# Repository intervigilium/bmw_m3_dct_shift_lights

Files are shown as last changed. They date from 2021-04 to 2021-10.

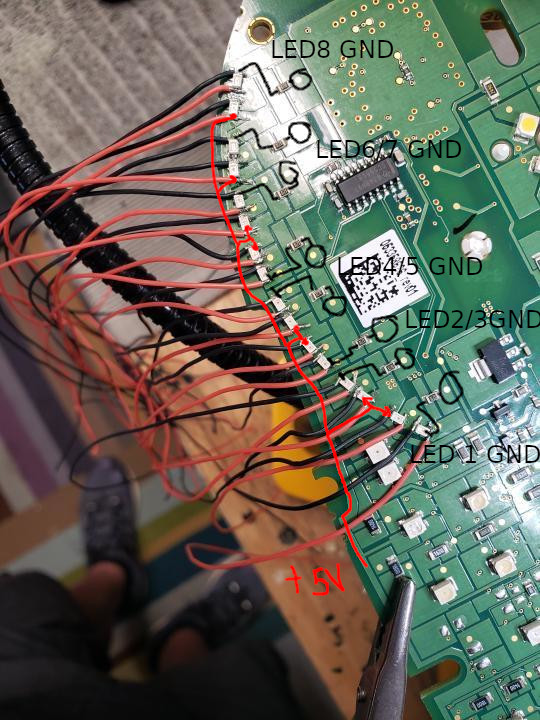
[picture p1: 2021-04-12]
m3_dct_shift_lights/m3_dct_cluster_gnd_points.jpg

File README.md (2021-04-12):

# BMW M3 DCT Cluster Shift Lights Retrofit

## BMW M3 DCT Cluster
The M3 DCT instrument cluster has a series of 8 shift lights above the
tachometer. These shift lights are normally not active, and do not appear to
be possible to activate without having the DCT itself. Fortunately, the
cluster's LEDs can be driven by attaching leads to the test points on the
ground side, as the LEDs are connected to an onboard 5V rail for power, and
a TI 6C596G4 8-bit shift register which acts as a current sink to ground.
Grounding each of these LED pairs will light up the corresponding pair.

## Retrofit circuit
Instead of attempting to drive the LEDs using the onboard TI 6C596 shift
register, we can just connect the LEDs to a shift register of our own and
connect that to an Arduino. The sketch here assumes that the shift register
is a TI 6C596 as well, and is configured using pins D3-D5, D18-D19. Engine
RPM for the BMW E9X series appears to be present on OBD2 port pin 9 as a 12V
square wave. This circuit utilizes the 12V RPM signal input circuit from
the Chippernut digital shift light project to read the signal, as well as
the 5V buck regulator input circuit to provide power.

## Cluster modifications
The M3 DCT cluster modifications necessary are detailed in the
`m3_dct_cluster_gnd_points.jpeg` file. Ignore the leads from the LEDs
themselves. The important points are circled in black, and correspond to the
ground points for the LED pairs. It is necessary to attach leads to these
ground points ONLY. You MUST attach leads to the test points AFTER the 127 Ohm
resistor (the highlighted points ONLY), not before. Failure to follow this
instruction will result in burning out the LEDs due to overcurrent.
You will also need to cut a small hole in the cluster enclosure to allow the LED
ground lines to connect to the Arduino.

## Schematic
The included `m3_dct_shift_lights.sch` file can be opened with any Eagle
schematic compatible program. The schematic only includes the circuit necessary
to read the RPM and control the LEDs. It does NOT include the necessary circuit
to independently power the Arduino from the car's +12V power sources. The
Chippernut development board
(<https://www.chippernut.com/store/p31/Chipperkit.html>) comes with a power
pack consisting of a 5V buck converter that can be used for this purpose.

## Components
The included `bom_m3_dct_shift_lights.csv` file contains the list of parts
necessary to build the circuit. The BOM list can easily purchased on Digikey.
It does not include the Arduino or a board to mount all the components. I
highly suggest using the above linked Chippernut development board pack, as it
comes with the 5V buck converter as well as a development board, Arduino nano,
and enclosure for installation.

## Installation
You will need to tap pin 9 of the OBD2 port for the tachometer signal. This
needs to be connected where the schematic says "To OBD2 Pin 9". You will also
need to provide power and ground, as well as connecting the 8 LED ground lines
from the M3 DCT cluster to the shift register (Refer to schematic where it
details the LED pairs with the notes that these are on board). I suggest
tapping +12V power and ground from the cluster connector pins 9 (+12V) and
18 (ground). I suspect the circuit must be connected to the cluster's ground
in order for the LEDs to function. The Arduino and wires can be tucked into
the driver's footwell under the panel. I chose to zip tie it near the firewall.

## Software Notes
The Arduino sketch has a few constants that can be customized to suit your
needs. The activation RPM and the maximum RPM values can be found at the top
of the file with the names `kActivationRpm` and `kMaxRpm`, respectively. The
`kActivationRpm` variable sets the RPM value at which the first LED will light.
The `kMaxRpm` variable sets the RPM value at which the all the LEDs will start
to flash. Any RPM value above the `kMaxRpm` value will mean the LEDs continue
to flash until the RPM drops below the threshold.

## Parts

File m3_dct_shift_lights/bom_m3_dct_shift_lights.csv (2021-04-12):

Manufacturer Part Number | Manufacturer | Digi-Key Part Number | Customer Reference | Reference Designator | Packaging | Part Status | Quantity | Unit Price | Extended Price | Quantity Available | Mfg Std Lead Time | Description | RoHS Status | Lead Free Status | REACH Status
SFH618A-2 | Vishay Semiconductor Opto Division | SFH618A-2-ND |  |  | Tube | Active | 1 | 0.97000 | $0.97 | 1754 | 37 Weeks | OPTOISOLATOR 5.3KV TRANS 4-DIP | ROHS3 Compliant | Lead free | Not Available
2N3906-G | Comchip Technology | 641-1946-ND |  |  | Bag | Active | 1 | 0.21000 | $0.21 | 15038 | 32 Weeks | TRANS PNP 40V 0.2A TO92 | ROHS3 Compliant | Lead free | REACH Unaffected
1N4148TA | ON Semiconductor | 1N4148TACT-ND |  |  | Cut Tape (CT) | Active | 1 | 0.10000 | $0.10 | 116115 | 34 Weeks | DIODE GEN PURP 100V 200MA DO35 | ROHS3 Compliant | Lead free | REACH Unaffected
MFP-25BRD52-10K | Yageo | 10KADCT-ND |  |  | Cut Tape (CT) | Active | 2 | 0.70000 | $1.40 | 213280 | 20 Weeks | RES 10K OHM 1/4W 0.1% AXIAL | ROHS3 Compliant | Lead free | REACH Unaffected
CF14JT7K50 | Stackpole Electronics Inc | CF14JT7K50CT-ND |  |  | Cut Tape (CT) | Active | 1 | 0.10000 | $0.10 | 26444 | 24 Weeks | RES 7.5K OHM 1/4W 5% AXIAL | ROHS3 Compliant | Lead free | REACH Unaffected
CF14JT47K0 | Stackpole Electronics Inc | CF14JT47K0CT-ND |  |  | Cut Tape (CT) | Active | 1 | 0.10000 | $0.10 | 190229 | 24 Weeks | RES 47K OHM 1/4W 5% AXIAL | ROHS3 Compliant | Lead free | REACH Unaffected
TPIC6C596N | Texas Instruments | 296-9015-5-ND |  |  | Tube | Active | 1 | 1.57000 | $1.57 | 794 | 6 Weeks | IC 8 BIT SHIFT REGISTER 16-DIP | ROHS3 Compliant | Lead free | REACH Unaffected

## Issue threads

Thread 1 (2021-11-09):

CAN bus suggestion

dzid26, 2021-11-09:
Cool project.
You could also use engine load to determine the optimal shiftpoints. (You can calculate optimal shift points for max acceleration based on [engine torque and known gear ratios](https://glennmessersmith.com/shiftpt.html#data), - though for non-turbo it's probably at top RPM anyways.. https://www.youtube.com/watch?v=zZBqb0ZJSwU)

Anyway, if you'd like, you can find engine torque on PT-CAN.
This message:
https://github.com/dzid26/opendbc-BMW-E8x-E9x/blob/59a48a6f48a842bf6da671ec5830d79149100d7a/bmw_e9x_e8x.dbc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
and this https://github.com/dzid26/opendbc-BMW-E8x-E9x/blob/59a48a6f48a842bf6da671ec5830d79149100d7a/bmw_e9x_e8x.dbc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

----------
The shift-lights CAN message is [**0x206**](https://www.spoolstreet.com/threads/m-drive-and-mdm-in-non-m-cars.7155/post-117085).

dzid26, 2021-12-07:
The shift-lights CAN message is [**0x206**](https://www.spoolstreet.com/threads/m-drive-and-mdm-in-non-m-cars.7155/post-117085).

dzid26, 2022-10-28:
He has done it https://github.com/superwofy/E9X-M-CAN-Integration-Module

Closed 2021-12-07.

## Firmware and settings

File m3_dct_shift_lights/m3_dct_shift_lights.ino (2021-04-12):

#include <avr/sleep.h>

const int kNumLeds = 8;
const int kIlluminationTimeMs = 200;

const int kShiftClockPin = 3;
const int kShiftRegClockPin = 6;
const int kShiftSerialInPin = 5;
const int kShiftClearPin = A3;
const int kShiftOutputEnablePin = A2;

const int kActivationRpm = 4000;
const int kMaxRpm = 6500;

struct Tach {
  volatile unsigned long interval;
  volatile unsigned long lastPulseTime;
  volatile int timeoutCounter;
  long currentRpm;
  int timeoutValue;
  int rpmPerPulse;
  int rpmPin;
};
struct Tach gTach;

struct Debug {
  bool enabled;
  int rpmDirection;
  int rpmSlope;
  int lastDebugRpm;
};
struct Debug gDebug;

struct Serial {
  bool enabled;
  uint64_t numCycles;
};
struct Serial gSerial;

void setupDebugMode(struct Debug& d) {
  const bool kDebug = false;
  const int kDebugRpmSlope = 200;

  d.enabled = kDebug;
  d.rpmDirection = 1;
  d.rpmSlope = kDebugRpmSlope;
  d.lastDebugRpm = kActivationRpm - d.rpmSlope;
}

void setupSerial(struct Serial& s) {
  const bool kEnableSerial = false;
  if (!kEnableSerial) {
    return;
  }

  s.enabled = kEnableSerial;
  s.numCycles = 0;

  Serial.begin(9600);
}

void printRpm(const struct Serial s, const int rpm) {
  if (!s.enabled) {
    return;
  }
  if (s.numCycles % 5 == 0) {
    Serial.print("Current RPM: ");
    Serial.print(rpm);
    Serial.println();
  }
}

void printLights(const struct Serial s, const int numLights) {
  if (!s.enabled) {
    return;
  }
  if (s.numCycles % 5 == 0) {
    Serial.print("LEDs to light: ");
    Serial.print(numLights);
    Serial.println();
  }
}

void updateCycles(struct Serial& s) {
  if (!s.enabled) {
    return;
  }
  s.numCycles++;
}

void enableLightOutput(bool enable) {
  // This pin is active-low
  digitalWrite(kShiftOutputEnablePin, enable ? LOW : HIGH);
}

void enableLightsUpTo(int idx) {
  if (idx < 0 || idx > kNumLeds) {
    return;
  }
  digitalWrite(kShiftRegClockPin, LOW);
  shiftOut(kShiftSerialInPin, kShiftClockPin, MSBFIRST, (1 << idx) - 1);
  digitalWrite(kShiftRegClockPin, HIGH);
}

void blinkLights(int interval) {
  digitalWrite(kShiftOutputEnablePin, HIGH);
  delay(interval / 2);
  digitalWrite(kShiftOutputEnablePin, LOW);
  delay(interval / 2);
}

int calculateNumLights(int currentRpm, int activationRpm, int maxRpm, int numLeds) {
  if (currentRpm < activationRpm) {
    return 0;
  }
  // 1 LED at activation RPM, all 8 LEDs at just under max RPM
  return 1 + ((numLeds * (currentRpm - activationRpm)) / (maxRpm - activationRpm));
}

int generateDebugRpm(struct Debug& d) {
  int rpm = d.lastDebugRpm;
  d.lastDebugRpm += (d.rpmSlope * d.rpmDirection);
  if (d.lastDebugRpm > (kMaxRpm + d.rpmSlope) ||
      d.lastDebugRpm < (kActivationRpm - d.rpmSlope)) {
    d.rpmDirection = -1 * d.rpmDirection;
  }
  return rpm;
}

int readRpm(struct Tach& t) {
  if (t.timeoutCounter > 0) {
    // Check for RPM signal shutting down
    t.timeoutCounter--;
  }
  if (t.timeoutCounter <= 0) {
    t.currentRpm = 0;
    return t.currentRpm;
  }

  // Calculate effective pulse interval in Hz
  float pulseRate = 1 / (t.interval * 1e-6);
  t.currentRpm = pulseRate * t.rpmPerPulse;
  return t.currentRpm;
}

void doSleep(const struct Tach t, const struct Serial s) {
  if (t.timeoutCounter > 0) {
    return;
  }
  sleep_enable();
  set_sleep_mode(SLEEP_MODE_PWR_DOWN);
    if (s.enabled) {
    Serial.println("Suspending due to no RPM input");
  }
  // Add delay to allow LED shutdown
  digitalWrite(LED_BUILTIN, LOW);
  delay(200);
  sleep_cpu();
}

void exitSleep(const struct Tach t) {
  // Sleep occurs if timeout counter drops below 1
  if (t.timeoutCounter > 0) {
    return;
  }
  digitalWrite(LED_BUILTIN, HIGH);
  sleep_disable();
}

void rpmIsr() {
  // Disable sleep mode if RPM ISR occurs while sleeping
  exitSleep(gTach);
  unsigned long now = micros();
  gTach.interval = now - gTach.lastPulseTime;
  gTach.lastPulseTime = now;
  gTach.timeoutCounter = gTach.timeoutValue;
}

void setupBuiltInLed() {
  pinMode(LED_BUILTIN, OUTPUT);
  digitalWrite(LED_BUILTIN, HIGH);
}

void setupShiftRegisterPins() {
  pinMode(kShiftSerialInPin, OUTPUT);
  pinMode(kShiftClockPin, OUTPUT);
  pinMode(kShiftRegClockPin, OUTPUT);
  pinMode(kShiftClearPin, OUTPUT);
  pinMode(kShiftOutputEnablePin, OUTPUT);

  // clear registers (active-low)
  digitalWrite(kShiftClearPin, LOW);
  delay(100);
  digitalWrite(kShiftClearPin, HIGH);
}

void setupRpmCalculation(struct Tach& t) {
  // number of cycles until until idle once RPM signal stops coming
  const int kTimeoutValue = 20;
  // BMW N51/N52 is 50Hz == 1000 RPM, 100Hz = 2000 RPM, or 20 RPM per pulse
  const int kRpmPerPulse = 20;
  // Pins 2/3 are the only external interrupt pins available on nano
  const int kRpmPin = 2;

  t.interval = 0;
  t.lastPulseTime = 0;
  t.timeoutCounter = 0;
  t.currentRpm = 0;
  t.timeoutValue = kTimeoutValue;
  t.rpmPerPulse = kRpmPerPulse;
  t.rpmPin = kRpmPin;

  pinMode(t.rpmPin, INPUT);
  attachInterrupt(digitalPinToInterrupt(t.rpmPin), rpmIsr, RISING);
}

// the setup routine runs once when you press reset:
void setup() {
  setupBuiltInLed();

  setupDebugMode(gDebug);

  setupSerial(gSerial);

  setupShiftRegisterPins();

  setupRpmCalculation(gTach);
}

// the loop routine runs over and over again forever:
void loop() {
  int rpm = gDebug.enabled ? generateDebugRpm(gDebug) : readRpm(gTach);
  printRpm(gSerial, rpm);
  int numLights = calculateNumLights(rpm, kActivationRpm, kMaxRpm, kNumLeds);
  printLights(gSerial, numLights);
  if (numLights > kNumLeds) {
    enableLightOutput(true);
    enableLightsUpTo(kNumLeds);
    blinkLights(kIlluminationTimeMs);
  } else if (numLights > 0) {
    enableLightOutput(true);
    enableLightsUpTo(numLights);
    delay(kIlluminationTimeMs);
  } else {
    // No lights enabled
    enableLightOutput(false);
    delay(kIlluminationTimeMs);
  }
  updateCycles(gSerial);
  doSleep(gTach, gSerial);
}

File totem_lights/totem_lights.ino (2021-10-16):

#include <Adafruit_NeoPixel.h>
#ifdef __AVR__
#include <avr/power.h>
#endif
#define PIN        6
#define NUMPIXELS 60

#define LED_BRIGHTNESS 200

#define NUM_MODES 4
int *counter;

Adafruit_NeoPixel pixels(NUMPIXELS, PIN, NEO_GRB + NEO_KHZ800);

void setup() {
  counter = (int *) malloc(sizeof(int));
  (*counter)++;

#if defined(__AVR_ATtiny85__) && (F_CPU == 16000000)
  clock_prescale_set(clock_div_1);
#endif

  pixels.begin();
}

void rainbow() {
  // Use 16 bits of color
  // Display the entire color gamut across the length of the strip.
  const int hueStep = 4096;
  for (uint64_t firstPixelHue = 0; firstPixelHue < 5 * 65536; firstPixelHue += hueStep) {
    for (int i = 0; i < pixels.numPixels(); i++) {
      // ColorHSV takes a hue from 0-65536
      const uint16_t hue = firstPixelHue + (i * 65536 / pixels.numPixels());
      const uint32_t color = pixels.gamma32(pixels.ColorHSV(hue));
      pixels.setPixelColor(i, color);
    }
    pixels.show();
    delay(50);
  }
}

void rainbowStreak() {
  // Use 16 bits of color
  // Display the entire color gamut across the length of the strip.
  const int startPixel = 24;
  const int length = pixels.numPixels() - startPixel;
  const int hueStep = 4096;
  const int streakLength = 20;
  for (uint64_t firstPixelHue = 0; firstPixelHue < 5 * 65536; firstPixelHue += hueStep) {
    for (int offset = startPixel - streakLength; offset < pixels.numPixels(); offset++) {
      pixels.clear();
      for (int i = 0; i < streakLength; i++) {
        // start at next offset
        const int pixel = i + offset;
        if (pixel < startPixel || pixel >= pixels.numPixels()) {
          continue;
        };
        // ColorHSV takes a hue (0-65536), saturation (0-255), brightness (0-255)
        const uint16_t hue = firstPixelHue + (pixel * 65536 / length);
        const uint32_t color = pixels.gamma32(pixels.ColorHSV(hue, 255, LED_BRIGHTNESS));
        pixels.setPixelColor(pixel, color);
      }
      pixels.show();
      delay(25);
    }
  }
}

void rainbowMarquee() {
  // Use 16 bits of color
  // Display the entire color gamut across the length of the strip.
  // Move the first hue by 4096
  const int iterations = 30;
  const int frames = 90;
  const int hueStep = 65536 / frames;
  uint16_t firstPixelHue = 0;
  for (int a = 0; a < iterations; a++) {
    for (int b = 0; b < frames / iterations; b++) {
      pixels.clear();
      for (int c = b; c < pixels.numPixels(); c += 3) {
        // ColorHSV takes a hue (0-65536), saturation (0-255), brightness (0-255)
        const uint16_t hue = firstPixelHue + (c * 65536 / pixels.numPixels());
        const uint32_t color = pixels.gamma32(pixels.ColorHSV(hue, 255, LED_BRIGHTNESS));
        pixels.setPixelColor(c, color);
      }
      pixels.show();
      delay(50);
      firstPixelHue += hueStep;
    }
  }
}

void colorPulse() {
  // Use 16 bits of color
  // Display a single color, vary the brightness to full, then dim before
  // cycling the color
  for (uint64_t hue = 0; hue < 5 * 65536; hue += 4096) {
    for (int brightnessCount = 0; brightnessCount < 256 * 2; brightnessCount += 31) {
      int brightness = brightnessCount;
      if (brightness > 256) {
        // Cause brightness value to decrease gradually
        brightness = 256 - (brightnessCount - 256);
      }
      for (int i = 0; i < pixels.numPixels(); i++) {
        // ColorHSV takes a hue (0-65536), saturation (0-255), brightness (0-255)
        const uint32_t color = pixels.gamma32(pixels.ColorHSV(hue, 255, brightness));
        pixels.setPixelColor(i, color);
      }
      pixels.show();
      delay(50);
    }
  }
}

void loop() {
  const int mode = abs((*counter) % NUM_MODES);
  switch (mode) {
    case 0:
      rainbow();
      break;
    case 1:
      rainbowStreak();
      break;
    case 2:
      rainbowMarquee();
      break;
    case 3:
      colorPulse();
      break;
    default:
      rainbow();
      break;
  }
}

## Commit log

2021-03-21 arduino: Add initial m3 cluster power tester
2021-04-04 power_tester: Light all LEDs up to index
2021-04-04 power_tester: Make pin constants constants
2021-04-04 power_tester: Only allow valid inputs to light function
2021-04-04 power_tester: Fix constant naming
2021-04-04 power_tester: Move serial input pin to 5
    * External interrupt must be on pin 2/3
2021-04-04 power_tester: Read RPM pin
2021-04-04 power_tester: Move shift register pin setup to function
2021-04-04 power_tester: Move RPM pin setup to function
2021-04-04 power_tester: Make RPM per pulse var const
2021-04-04 power_tester: Activate LEDs based on RPM
2021-04-04 power_tester: Remove unused variable
2021-04-04 power_tester: Add RPM scaling test mode
2021-04-04 power_tester: Reverse RPM tester direction
2021-04-04 power_tester: Disable lights if no lights need lighting
2021-04-04 power_tester: Illuminate debug RPM for 200ms
2021-04-04 power_tester: Make blink timing comment accurate
2021-04-04 power_tester: Fix last LED enable at max RPM
    * Account for the fact that we want the last LED segment to be on just
    before it reaches max RPM, as once max RPM is reached, the system will
    begin to blink all the LEDs.
2021-04-04 power_tester: Ensure all illumination paths cycle for 200ms
2021-04-04 power_tester: Cycle between activation and max RPM only when debugging
2021-04-04 power_tester: Use constant for illumination time
2021-04-04 power_tester: Move debug RPM generation to function
2021-04-04 power_tester: Add comment about interrupt pins
2021-04-04 power_tester: Reduce startup clear delay
2021-04-09 Print RPM periodically
2021-04-10 Update pins for actual circuit board
2021-04-11 Fix debug RPM initial state
    [m3_dct_shift_lights.ino]
2021-04-12 Allow Arduino to power down if no RPM signal present
2021-04-12 Move RPM pin into Tach struct as well
2021-04-12 Add circuit schematic
    [m3_dct_shift_lights.sch]
2021-04-12 Add parts BOM from Digikey
    [bom_m3_dct_shift_lights.csv]
2021-04-12 Add cluster ground points
2021-04-12 Update schematic, move to center of sheet
    [m3_dct_shift_lights.sch]
2021-10-10 totem_lights: fix file hierarchy
    [totem_lights.ino]
2021-10-10 totem_lights: neopixel sample code import
2021-10-16 totem_lights: Switch mode using reset
    [totem_lights.ino]
2022-05-02 pack_lights: Import gemma m0 circuitpython code
2022-05-02 pack_lights: Replace with dynamic listening code
    [code.py]
2022-05-06 pack_lights: Use full LED range
